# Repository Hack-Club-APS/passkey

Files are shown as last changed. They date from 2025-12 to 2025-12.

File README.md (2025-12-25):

# Passkey
This passkey is made so that the user can login without using a password. Using the picokeys firmware for raspberry pi microcontrollers, it is pretty secure(FIDO2) and fun to use. Even though it has a small form factor, it carries one button and a white LED - enough for passwordless login and some custom HID stuff.  
  
  
  
  
view this project on [KiCanvas](http://kicanvas.org/?github=https://github.com/Hack-Club-APS/passkey/tree/main/aps_passkey_hardware)!  

## Bill Of Materials:
| Item | Cost  | Note |
|---|---|---|
| PCB | 2 | from jlcpcb |
| PCBA | 44.31 | |
| Shipping charges | 11.39 | |
| Discount | -9 | |
| Total | 48.70 | USD |

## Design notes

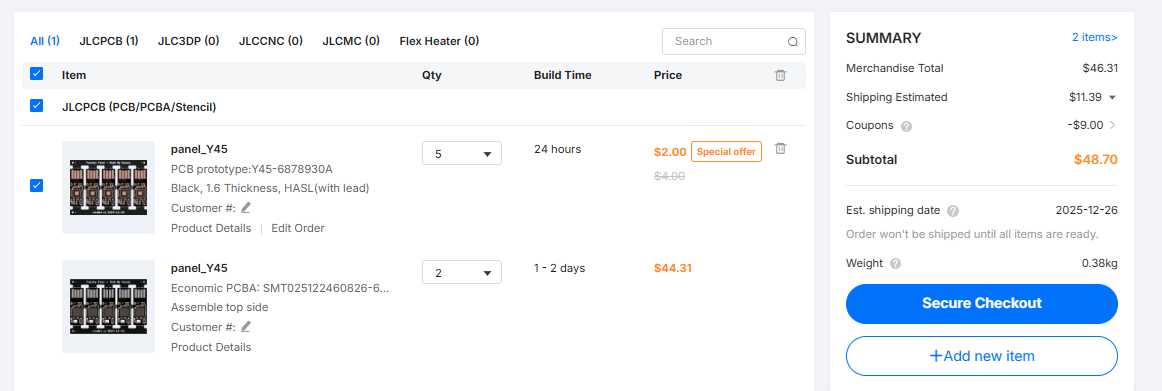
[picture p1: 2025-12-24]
cart.png

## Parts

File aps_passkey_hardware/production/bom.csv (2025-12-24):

Designator | Footprint | Quantity | Value | LCSC Part #
C1, C18, C2, C21, C3, C6 | 0402 | 6 | 4.7u
C10, C11, C12, C13, C14, C15, C16, C17, C7, C8, C9 | 0402 | 11 | 100n
C19, C20 | 0603 | 2 | 10u
C4, C5 | 0402 | 2 | 33p
D1 | 0603 | 1 | LED
J1 | USBPCB | 1 | USB_A
L1 | IND-SMD_L2.0-W1.6_AOTA-B201610S3R3-101-T | 1 | AOTA | C42411119
R1 | 0402 | 1 | 33
R2, R3 | 0402 | 2 | 27R
R4, R5, R6 | 0402 | 3 | 1k
SW1 | SW-SMD_L3.9-W3.0-P4.45 | 1 | SW_Push
U1 | RP2350A_QFN-60_EP_7.75x7.75_Pitch0.4mm | 1 | RP2350A-QFN60
U2 | X2SON-4_L1.0-W1.0-P0.65-TL-EP | 1 | TLV75512PDQNR | C2867150
Y1 | Crystal_SMD_3225-4Pin_3.2x2.5mm | 1 | Crystal_GND24

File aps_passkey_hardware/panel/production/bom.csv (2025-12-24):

Designator | Footprint | Quantity | Value | LCSC Part #
C1_5, C1_4, C1_3, C1_2, C1, C18_5, C18_4, C18_3, C18_2, C18, C2_5, C2_4, C2_3, C2_2, C2, C21_5, C21_4, C21_3, C21_2, C21, C3_5, C3_4, C3_3, C3_2, C3, C6_5, C6_4, C6_3, C6_2, C6 | 0402 | 30 | 4.7u
C10_5, C10_4, C10_3, C10_2, C10, C11_5, C11_4, C11_3, C11_2, C11, C12_5, C12_4, C12_3, C12_2, C12, C13_5, C13_4, C13_3, C13_2, C13, C14_5, C14_4, C14_3, C14_2, C14, C15_5, C15_4, C15_3, C15_2, C15, C16_5, C16_4, C16_3, C16_2, C16, C17_5, C17_4, C17_3, C17_2, C17, C7_5, C7_4, C7_3, C7_2, C7, C8_5, C8_4, C8_3, C8_2, C8, C9_5, C9_4, C9_3, C9_2, C9 | 0402 | 55 | 100n
C19_5, C19_4, C19_3, C19_2, C19, C20_5, C20_4, C20_3, C20_2, C20 | 0603 | 10 | 10u
C4_5, C4_4, C4_3, C4_2, C4, C5_5, C5_4, C5_3, C5_2, C5 | 0402 | 10 | 33p
D1_5, D1_4, D1_3, D1_2, D1 | 0603 | 5 | LED
J1_5, J1_4, J1_3, J1_2, J1 | USBPCB | 5 | USB_A
L1_5, L1_4, L1_3, L1_2, L1 | IND-SMD_L2.0-W1.6_AOTA-B201610S3R3-101-T | 5 | AOTA | C42411119
R1_5, R1_4, R1_3, R1_2, R1 | 0402 | 5 | 33
R2_5, R2_4, R2_3, R2_2, R2, R3_5, R3_4, R3_3, R3_2, R3 | 0402 | 10 | 27R
R4_5, R4_4, R4_3, R4_2, R4, R5_5, R5_4, R5_3, R5_2, R5, R6_5, R6_4, R6_3, R6_2, R6 | 0402 | 15 | 1k
SW1_5, SW1_4, SW1_3, SW1_2, SW1 | SW-SMD_L3.9-W3.0-P4.45 | 5 | SW_Push
U1_5, U1_4, U1_3, U1_2, U1 | RP2350A_QFN-60_EP_7.75x7.75_Pitch0.4mm | 5 | RP2350A-QFN60
U2_5, U2_4, U2_3, U2_2, U2 | X2SON-4_L1.0-W1.0-P0.65-TL-EP | 5 | TLV75512PDQNR | C2867150
Y1_5, Y1_4, Y1_3, Y1_2, Y1 | Crystal_SMD_3225-4Pin_3.2x2.5mm | 5 | Crystal_GND24

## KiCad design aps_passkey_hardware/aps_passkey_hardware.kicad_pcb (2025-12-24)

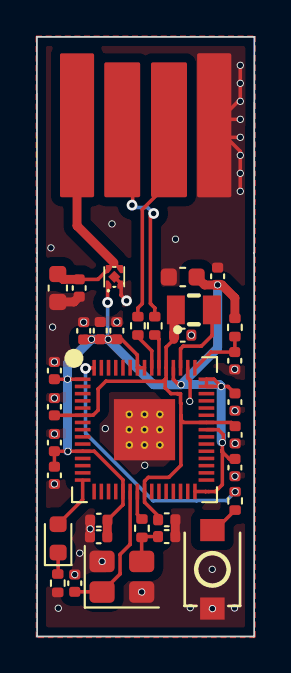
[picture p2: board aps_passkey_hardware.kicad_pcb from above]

Board: 2 copper layers, 12.1 x 33.3 mm, 34 parts (0 on the bottom side), 17 nets.

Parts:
C1, C2, C3, C6, C18, C21: 4.7u; C_0402_1005Metric
C4, C5: 33p; C_0402_1005Metric
C7, C8, C9, C10, C11, C12, C13, C14, C15, C16, C17: 100n; C_0402_1005Metric
C19, C20: 10u; C_0603_1608Metric
D1: LED; LED_0603_1608Metric
J1: USB_A; USBPCB
L1: AOTA; IND-SMD_L2.0-W1.6_AOTA-B201610S3R3-101-T
R1: 33; R_0402_1005Metric
R2, R3: 27R; R_0402_1005Metric
R4, R5, R6: 1k; R_0402_1005Metric
SW1: SW_Push; SW-SMD_L3.9-W3.0-P4.45
U1: RP2350A-QFN60; RP2350A_QFN-60_EP_7.75x7.75_Pitch0.4mm
U2: TLV75512PDQNR; X2SON-4_L1.0-W1.0-P0.65-TL-EP
Y1: Crystal_GND24; Crystal_SMD_3225-4Pin_3.2x2.5mm

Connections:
+1V1: C1.1, C6.1, C7.1, C8.1, L1.2, U1.6 (DVDD), U1.23 (DVDD), U1.39 (DVDD), U1.50 (VREG_FB)
+3V3: C3.1, C9.1, C10.1, C11.1, C12.1, C13.1, C14.1, C15.1, C16.1, C17.1, C18.1, C19.1, R1.1, U1.1 (IOVDD), U1.11 (IOVDD), U1.20 (IOVDD), U1.30 (IOVDD), U1.38 (IOVDD), U1.44 (ADC_AVDD), U1.45 (IOVDD), U1.49 (VREG_VIN), U1.53 (USB_OTP_VDD), U1.54 (QSPI_IOVDD), U2.1 (OUT)
/TR+: R2.1, U1.52 (USB_DP)
/TR-: R3.1, U1.51 (USB_DM)
D+: J1.3 (D+), R2.2
D-: J1.2 (D-), R3.2
GND: C1.2, C2.2, C3.2, C4.2, C5.2, C6.2, C7.2, C8.2, C9.2, C10.2, C11.2, C12.2, C13.2, C14.2, C15.2, C16.2, C17.2, C18.2, C19.2, C20.2, C21.2, J1.4 (GND), R6.2, SW1.1, U1.47 (VREG_PGND), U1.61 (GND), U2.2 (GND), U2.5 (EP), Y1.2, Y1.4
unnamed: D1.2 (A), U1.15 (GPIO11)
unnamed: D1.1 (K), R6.1
unnamed: C20.1, C21.1, J1.1 (VBUS), U2.3 (EN), U2.4 (IN)
unnamed: R4.1, SW1.2
unnamed: C2.1, R1.2, U1.46 (VREG_AVDD)
unnamed: L1.1, U1.48 (VREG_LX)
unnamed: R5.2, U1.22 (XOUT)
QSPI_SS: R4.2, U1.60 (QSPI_SS)
XIN: C4.1, U1.21 (XIN), Y1.1
XOUT: C5.1, R5.1, Y1.3

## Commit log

2025-12-07 Hello World!
    [aps_passkey_hardware.kicad_pcb, aps_passkey_hardware.kicad_sch]
2025-12-09 new design
    [aps_passkey_hardware.kicad_pcb, aps_passkey_hardware.kicad_sch]
2025-12-11 PCB Done
    [aps_passkey_hardware.kicad_pcb, aps_passkey_hardware.kicad_sch]
2025-12-24 added silkscreen+panelisation part
    [aps_passkey_hardware.kicad_pcb, bom.csv, designators.csv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]
2025-12-24 fixed ground errors
    [aps_passkey_hardware.kicad_pcb, bom.csv, designators.csv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]
2025-12-24 added BOM
    [bom.csv]
